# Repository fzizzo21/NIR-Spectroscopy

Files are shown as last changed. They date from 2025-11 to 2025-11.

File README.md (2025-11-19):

# NIR-Spectroscopy
A 2-band NIR spectroscopy platform, with the intention of differentiating between cotton and polyester fabrics

This project was made after being curious about scientifically differentiating between these fabrics when purchasing clothes with unknown material content, especially used clothing. I thought there had to be an affordable way to do this already out there, but the cheapest device I found which can do this (easily, and portable) was about $3000 USD. This device was made with the intention of being simple and affordable, to manufacture, or purchase, if need be. 

The general idea is to pulse some infared emitter (in this project I am using 2 discrete bands rather than a wideband emitter) and receive the reflections off of the fabric with a photodiode. This photodiode signal is amplified, and demodulated, to figure out some DC level that corresponds to the reflected light off of the fabric. Cotton and polyester have much differing absorption characteristics at these wavelengths, so we can use this to differentiate between the two. I chose to use 2 discrete bands to keep costs down, and for simplicity, as I believe some higher cost alternatives use wideband emitters then optical filters, but I didn't really want to deal with optical filters and their associated costs at these wavelenths, so I am using 2 discrete emitters and normalizing them with a calibration using white PTFE sheets, and black velvet fabric. 

The emitters are part numbers MTE6114W-WRC and MTE5116W-WRC, with the sensor being MTPD1346D-010. I used the ESP32 as the microcontroller for the option to sending results to a phone over bluetooth or wifi, although I haven't worked on this development yet. The ADC is a TLA2518, as it samples fast enough for demodulation, and is relatively cheap and simple, communicating over SPI. The demodulation is done to overcome noisy environments, or possibly other NIR sources (such as heat sources), so the emitters are just PWM'ed at around 5kHz so that I know what to look for, than demodulated in hardware by essentially chopping the received signal with a 5kHz synchronized square wave to get close to a DC level (shifting the 5kHz), and filtering out other frequencies. There is also the option to just do this in software.

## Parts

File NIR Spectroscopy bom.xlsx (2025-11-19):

Line # | Name | Description | Designator | Revision ID | Revision State | Revision Status | Quantity | Manufacturer 1 | Manufacturer Part Number 1 | Manufacturer Lifecycle 1 | Supplier 1 | Supplier Part Number 1 | Supplier Unit Price 1 | Supplier Subtotal 1
 | 691210910002 |  | 1450, 1650, PWR, RX | CMP-1502-02456-2 | Released | Up to date | 4 | Wurth Elektronik | 691210910002 | Unknown | RS (Formerly Allied Electronics) | 74394624 | 0.48 | 1.92
 | CL10A225KO8NNNC | Cap Ceramic 2.2uF 16V X5R ±10% Pad SMD 0603 +85°C T/R | C1, C2, C4, C5 | CMP-13271-000835-1 | New From Design | Up to date | 4 | Samsung Electro-Mechanics | CL10A225KO8NNNC | Volume Production | DigiKey | 1276-1040-1-ND | 0.009 | 0.09
 | CL05B104KO5NNNC | Chip Capacitor, 100 nF, +/- 10%, 16 V, -55 to 125 degC, 0402 (1005 Metric), RoHS, Tape and Reel | C3, C7, C9, C11, C13, C15, C16, C18, C19, C20, C21, C23, C24 | CMP-2000-05439-1 | Released | Up to date | 13 | Samsung Electro-Mechanics | CL05B104KO5NNNC | Volume Production | DigiKey | 1276-1001-1-ND | 0.009 | 0.117
 | CL05A105KA5NQNC | Cap Ceramic 1uF 25V X5R ±10% SMD 0402 +85°C Paper T/R | C6, C10, C12, C14 | CMP-13271-001051-1 | New From Design | Up to date | 4 | Samsung Electro-Mechanics | CL05A105KA5NQNC | Volume Production | Mouser | 187-CL05A105KA5NQNC | 0.021 | 0.21
 | 22 µF | CAP CER 22UF 6.3V X5R 0603 | C8 |  | Not managed |  | 1 | Samsung Electro-Mechanics | CL10A226KQ8NRNE | Volume Production | DigiKey | 1276-2867-1-ND | 0.43 | 0.43
 | 47pF | Capacitor 0402CG470J500NT | C17 |  | Not managed |  | 1
 | CL05B103KB5NNNC | Cap Ceramic 10nF 50V X7R ±10% SMD 0402 +125°C Paper T/R | C22 | CMP-13271-000387-1 | New From Design | Up to date | 1 | Samsung Electro-Mechanics | CL05B103KB5NNNC | Volume Production | Farnell | 3013345 | 0.00566 | 0.05658
 | CL10B221KB8NNNC | Cap Ceramic 220pF 50V X7R ±10% Pad SMD 0603 +125°C T/R | C25 | CMP-13271-000087-1 | New From Design | Up to date | 1 | Samsung Electro-Mechanics | CL10B221KB8NNNC | Volume Production | DigiKey | 1276-1145-1-ND | 0.1 | 0.1
 | Green | LED GREEN CLEAR 0805 SMD KT0805G | D1 |  | Not managed |  | 1 | Bivar | SM0805GC | Volume Production | DigiKey | 492-1696-1-ND | 0.98 | 0.98
 | BLM18PG121SN1D | Chip Ferrite Bead, 0603, 120Ω @ 100MHz, 0.05Ω, 25%, 2A | FB1 | CMP-0686-00557-7 | Released | Up to date | 1 | Murata | BLM18PG121SN1D | Volume Production | Mouser | 81-BLM18PG121SN1D | 0.1 | 0.1
 | AL5816QW5-7 | Integrated Circuit | IC1, IC2 |  | Not managed |  | 2
 | Micro USB | CONN RCPT USB2.0 MICRO B SMD R/A | MCU1 |  | Not managed |  | 1 | Amphenol Communications Solutions | 10118193-0001LF | Volume Production | DigiKey | 609-4616-2-ND | 0.2614 | 313.68
 | AO3400A | MOSFET N-CH 30V 5.7A SOT23 | Q1, Q2 | CMP-83955-000006-1 | New From Design | Up to date | 2 | Alpha & Omega Semiconductor | AO3400A | Volume Production | DigiKey | 785-1000-1-ND | 0.46 | 0.92
 | 0 Ohms | 0805 0 ohm - use 0805W8F0000T5E | R1 |  | Not managed |  | 1 | KOA Speer | TLRZ2ATTD | Volume Production | DigiKey | 2019-TLRZ2ATTDCT-ND | 0.39 | 0.39
 | 1.5 kOhms | RES 1.5K OHM 1% 1/16W 0402 | R2 |  | Not managed |  | 1 | Stackpole Electronics | RMCF0402FT1K50 | Volume Production | DigiKey | RMCF0402FT1K50CT-ND | 0.1 | 0.1
 | 10 kOhms | RES SMD 10K OHM 1% 1/16W 0402 | R3, R12, R14, R15, R17, R18, R19 |  | Not managed |  | 7 | Vishay | CRCW040210K0FKEE | Volume Production | DigiKey | 541-2954-1-ND | 0.03 | 0.3
 | 1 kOhms | RES SMD 1K OHM 0.1% 1/16W 0402 | R4, R10, R16 |  | Not managed |  | 3 | TE Connectivity | CPF0402B1K0E | Volume Production | DigiKey | A119928CT-ND | 0.19 | 0.57
 | 22 Ohms | RES SMD 22 OHM 0.5% 1/16W 0402 | R5, R6, R7 |  | Not managed |  | 3 | Susumu | RR0510R-220-D | Not Recommended for New Design | DigiKey | RR05R22DCT-ND | 0.024 | 0.24
 | 6.8 Ohms | RES 6.8 OHM 1% 1/16W 0402 | R8 |  | Not managed |  | 1 | Stackpole Electronics | RMCF0402FT6R80 | Volume Production | DigiKey | RMCF0402FT6R80CT-ND | 0.1 | 0.1
 | 10 Ohms | RES SMD 10 OHM 5% 1/10W 0402 | R9 |  | Not managed |  | 1 | Panasonic | ERJ-2GEJ100X | Volume Production | DigiKey | P10JCT-ND | 0.1 | 0.1
 | 4.7 kOhms | RES SMD 4.7K OHM 0.5% 1/16W 0402 | R11 |  | Not managed |  | 1 | Susumu | RR0510P-472-D | Not Recommended for New Design | DigiKey | RR05P4.7KDCT-ND | 0.1 | 0.1
 | 100 Ohms | RES SMD 100 OHM 0.5% 1/16W 0402 | R13 |  | Not managed |  | 1 | Susumu | RR0510P-101-D | Not Recommended for New Design | DigiKey | RR05P100DCT-ND | 0.1 | 0.1
 | TS-1187A-B-A-B | Switch | S1 |  | Not managed |  | 1
 | MIC5528-3.3YMT-TR | IC REG LINEAR 3.3V 500MA 6TDFN | U1 | CMP-06324-000078-1 | New From Design | Up to date | 1 | Microchip | MIC5528-3.3YMT-TR | Volume Production | Newark | 03AJ2192 | 0.14 | 0.14
 | ESP32-C6-MINI-1-N4 | 802.15.4, Bluetooth, WiFi 802.11ax, Bluetooth v5.0, ZigbeeÂ® Transceiver Module 2.4GHz Antenna Not Included Surface Mount | U2 |  | Not managed |  | 1
 | TLA2518IRTER | IC ADC 12BIT SAR 16WQFN | U3 | CMP-04860-000058-1 | New From Design | Up to date | 1 | Texas Instruments | TLA2518IRTER | Volume Production | Mouser | 595-TLA2518IRTER | 3.09 | 3.09
 | OPA2320AIDR | Precision, 20 MHz, 0.9 pA Ib, RRIO, CMOS Operational Amplifier, 1.8 to 5.5 V, -40 to 125 degC, 8-pin SOIC (D8), Green (RoHS & no Sb/Br) | U4, U5 | CMP-0272-00771-3 | Released | Up to date | 2 | Texas Instruments | OPA2320AIDR | Volume Production | Arrow Electronics | OPA2320AIDR | 2.36 | 4.71
 | SN74LVC1G66DCKR | IC SWITCH 1X1 SC70-5 | U6 | CMP-0859-00385-4 | New From Design | Up to date | 1 | Texas Instruments | SN74LVC1G66DCKR | Volume Production | DigiKey | 296-13254-1-ND | 0.15 | 0.15
 | SN74LVC1G17DCKR | IC BUF NON-INVERT 5.5V SC70-5 | U7 | CMP-0859-00388-5 | New From Design | Up to date | 1 | Texas Instruments | SN74LVC1G17DCKR | Volume Production | DigiKey | 296-11934-1-ND | 0.14 | 0.14
 | 50kOhms | Trimmer, Cermet, Rest 50 Kilohms, SMD, 1 Turn, Pwr-Rtg 0.25W | Bourns 3314J-1-503E | VR1, VR2 |  | Not managed |  | 2

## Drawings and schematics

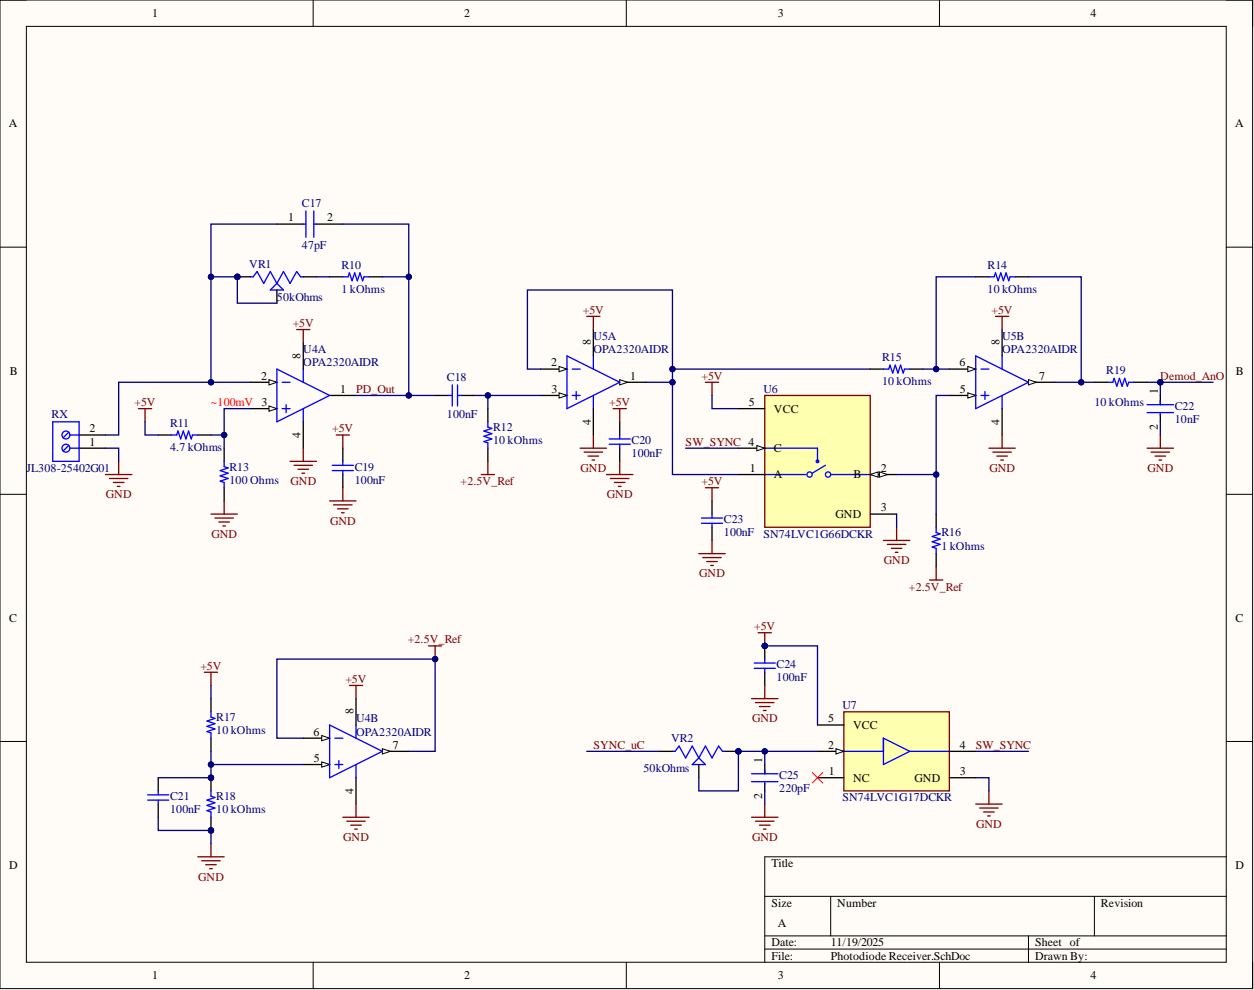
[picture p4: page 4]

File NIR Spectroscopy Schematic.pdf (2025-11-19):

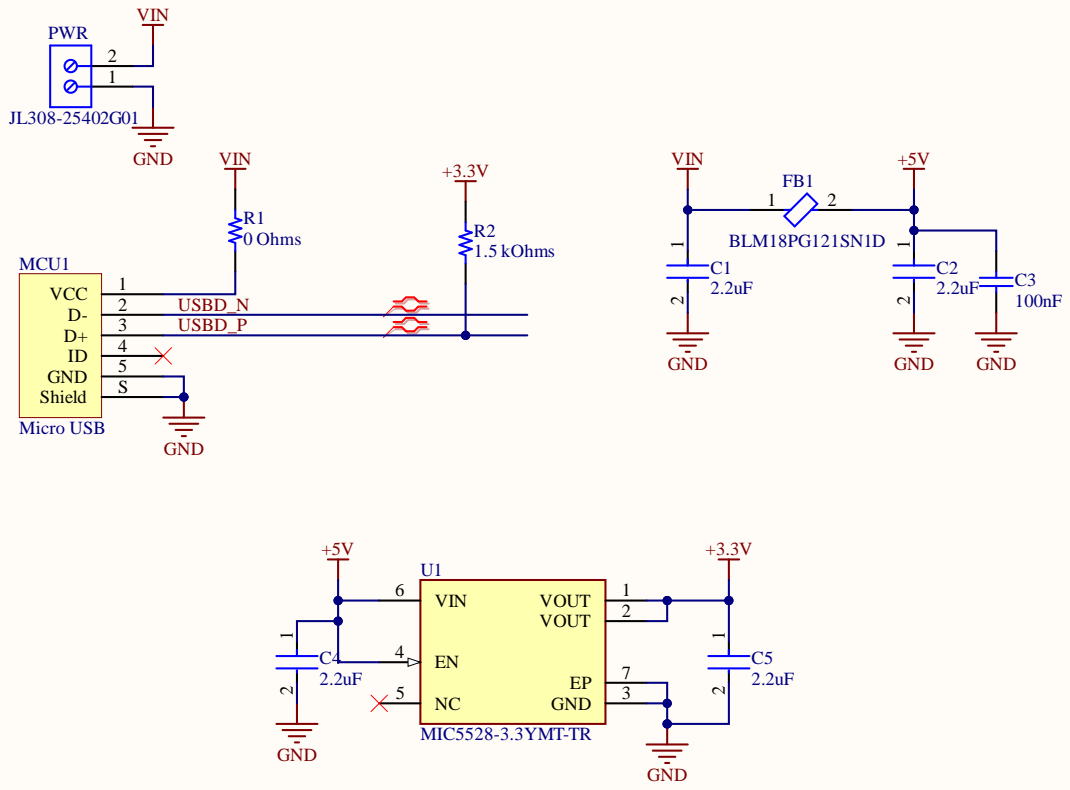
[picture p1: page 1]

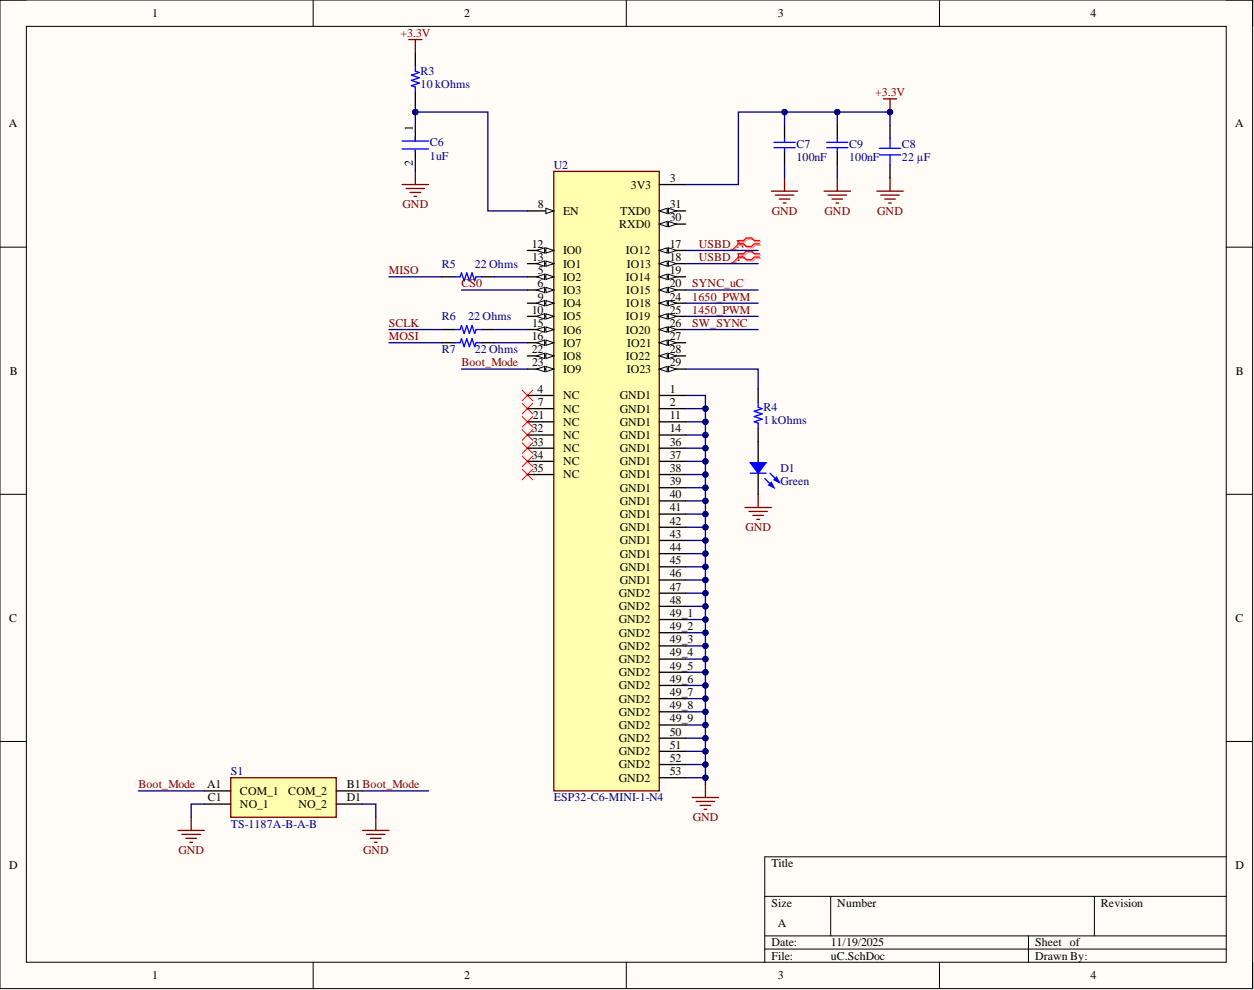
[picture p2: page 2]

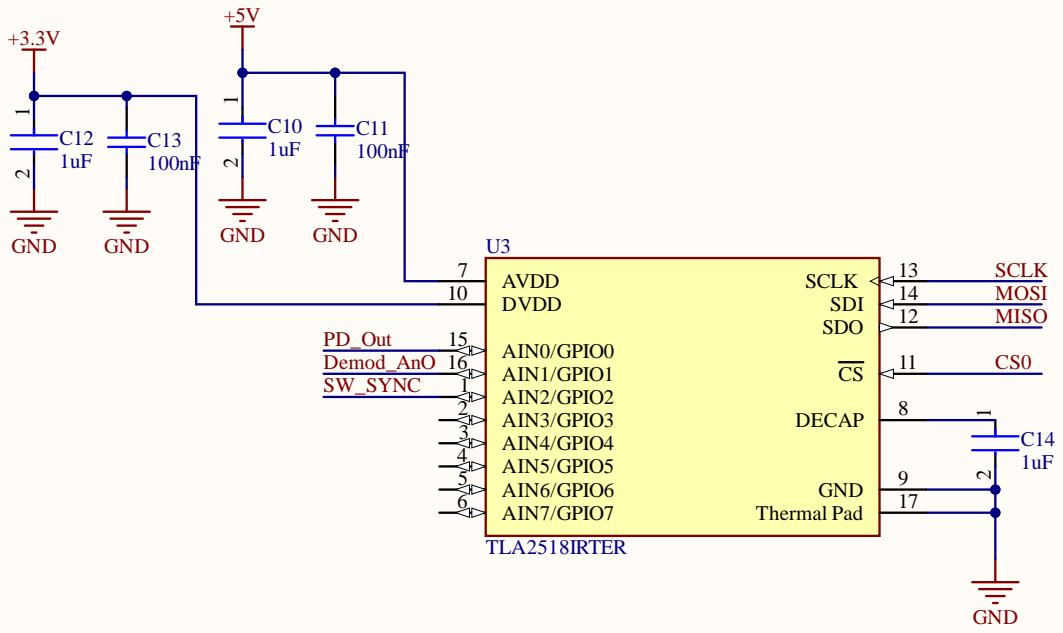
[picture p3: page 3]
hermal Pad
